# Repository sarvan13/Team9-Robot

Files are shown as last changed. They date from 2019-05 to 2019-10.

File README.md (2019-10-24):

# Team9 - Hedwig

## Hedwig went undefeated in competition!

This repository is contains all of the work that Team 9 (Alex Carbo, Maxwell Yang, Kausik Krishnakumar, Sarvan Gill) produced throughout their summer, with the main focus being on building a fully autonomous robot for a robot competition in August 2019. 

The **ENPH257/** folder contains MATLAB scripts (including data), to investigate thermal waves through the heating of an alumninium rod.

All other folders are pertaining to the robot.

## Robot
Link to the rules and structure of the competition: https://docs.google.com/document/d/1WXgxAmkSgfv2YprMDtSkUyIwbtqzgsT3AemDqi9obIw/edit

Link to news clip on the competition:
https://www.facebook.com/BTCityNewsVAN/videos/583404632190468/

### Microcontrollers
We used 2 STM-32 microcontrollers, giving us a single master controller and a single slave controller. The master handled the navigation aspect of the competition, while the slave controlled the arm movements. The master ran the **robot_test_code/** folder and the slave ran the **slave_code/** folder. 

### CAD
All CAD is in the **Solidworks/** folder. The main assembly is **Robot_V1.SLDASM**. When opening this file it may ask for the loaction of the other files, in which case just point to the correct files. Do not move the files after it has opened. 

The .dxf are the files used to cut the parts using either a laser jet cutter or a water jet cutter. The main purpose of the CAD, was to produce these files for cutting and measurment purposes, so in almost all cases these files were just exported from their respective Solidworks part.

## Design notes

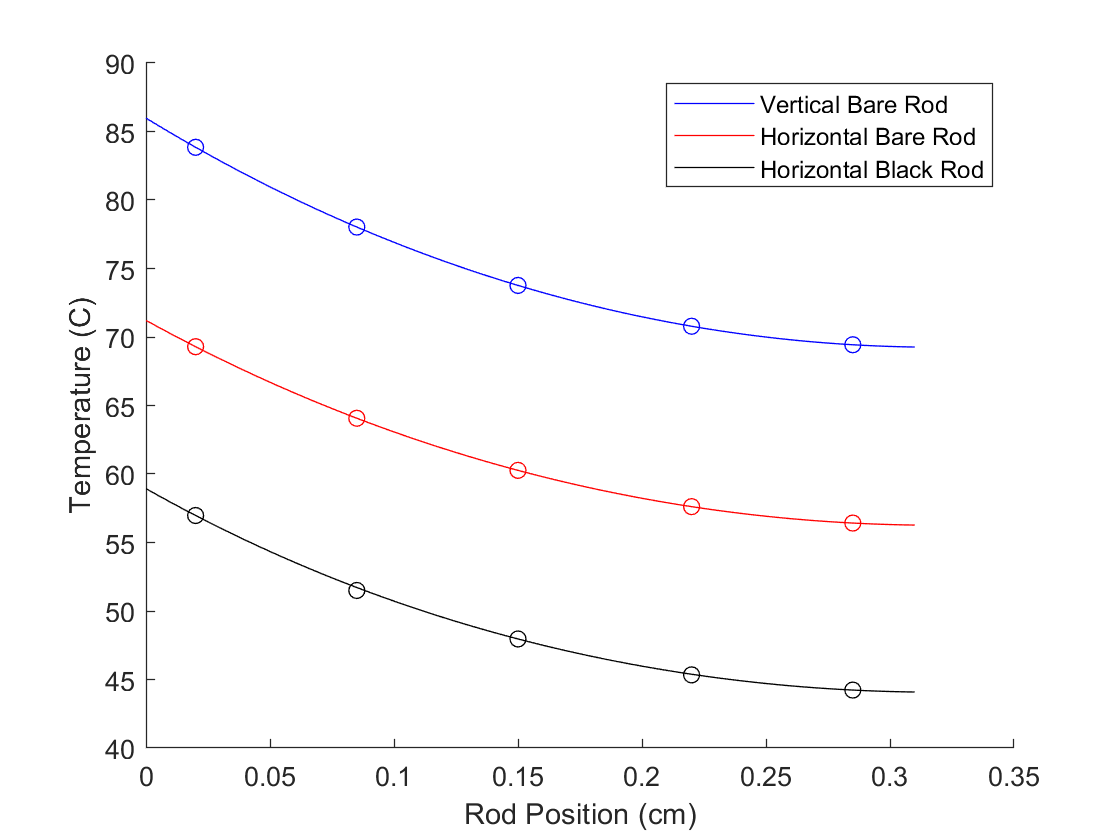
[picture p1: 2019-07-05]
ENPH257/maxwells_sextape_highlights.png

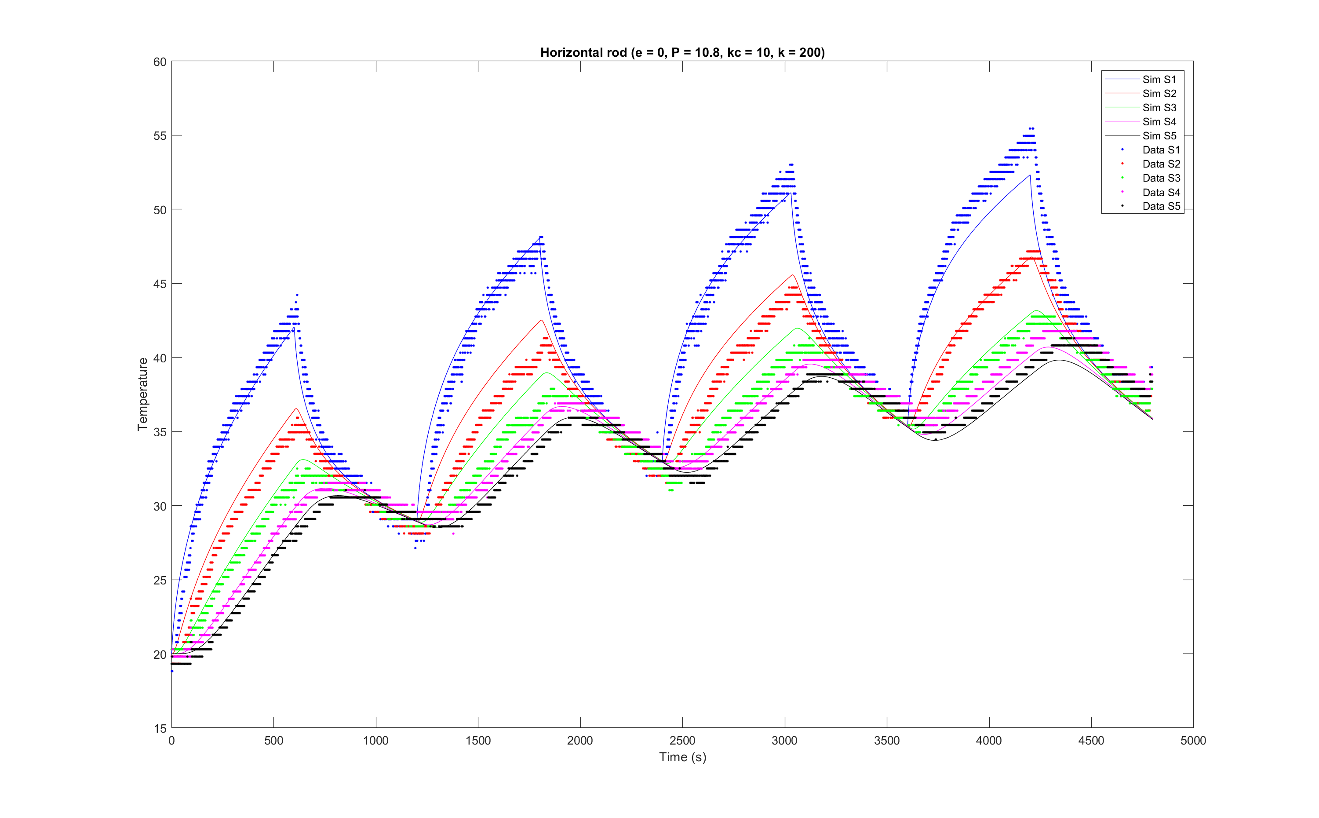
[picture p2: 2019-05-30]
ENPH257/Horizontal(P=10.8,kc=10,k=200).png

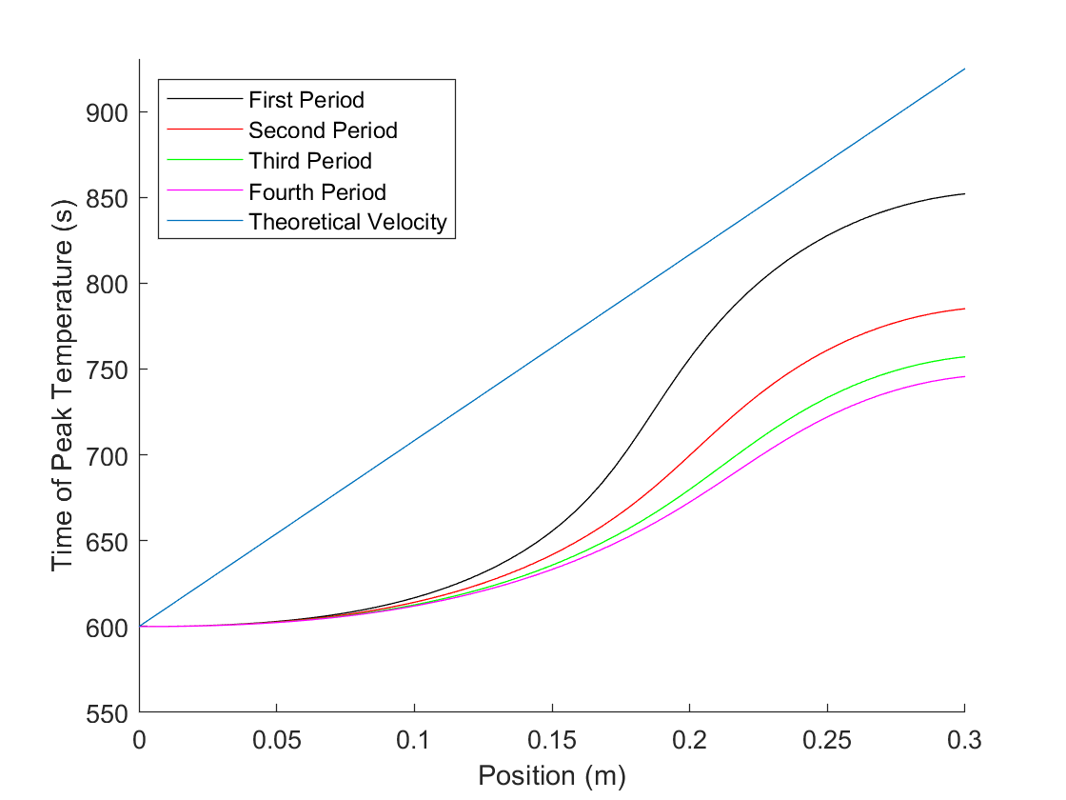
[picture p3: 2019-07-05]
ENPH257/Vala.png

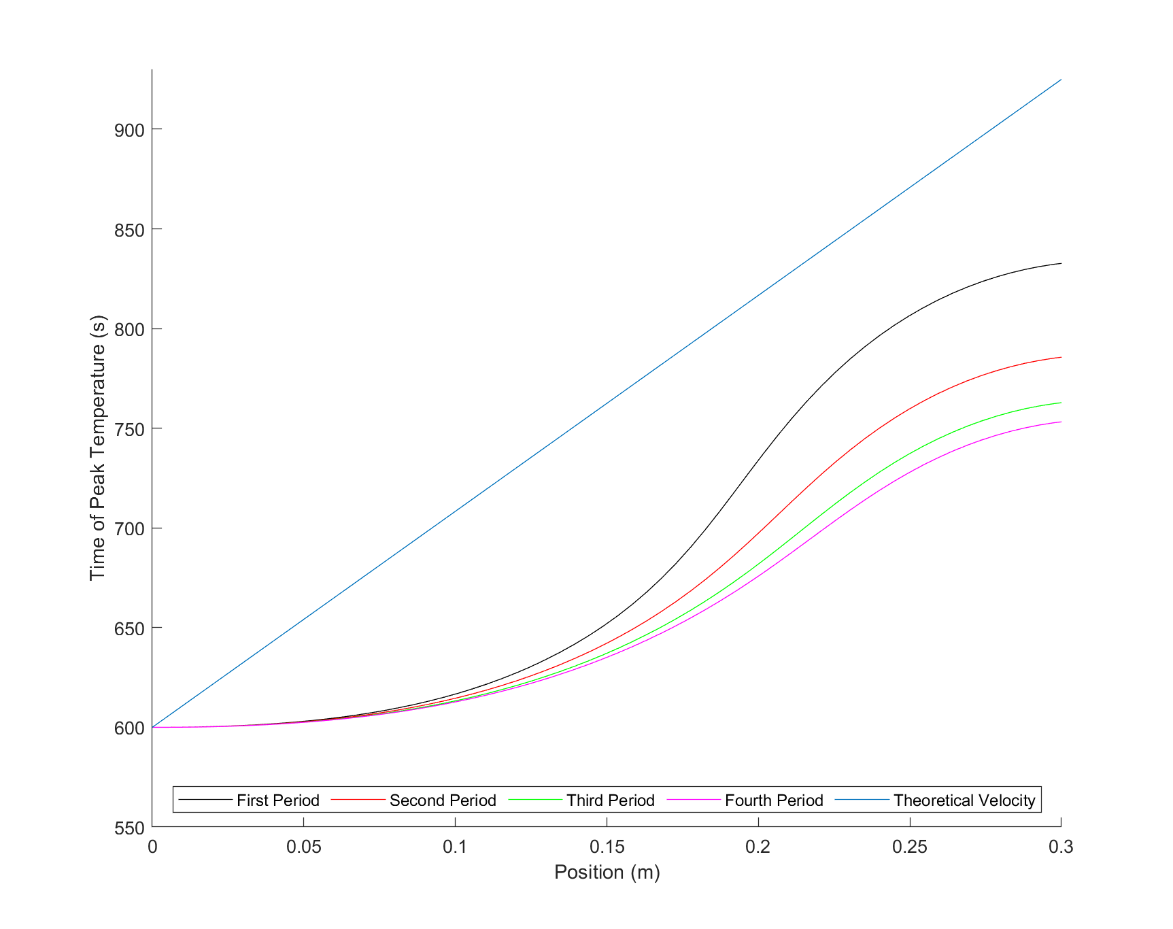
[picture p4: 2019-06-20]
ENPH257/ThermoWaveVelocity.png

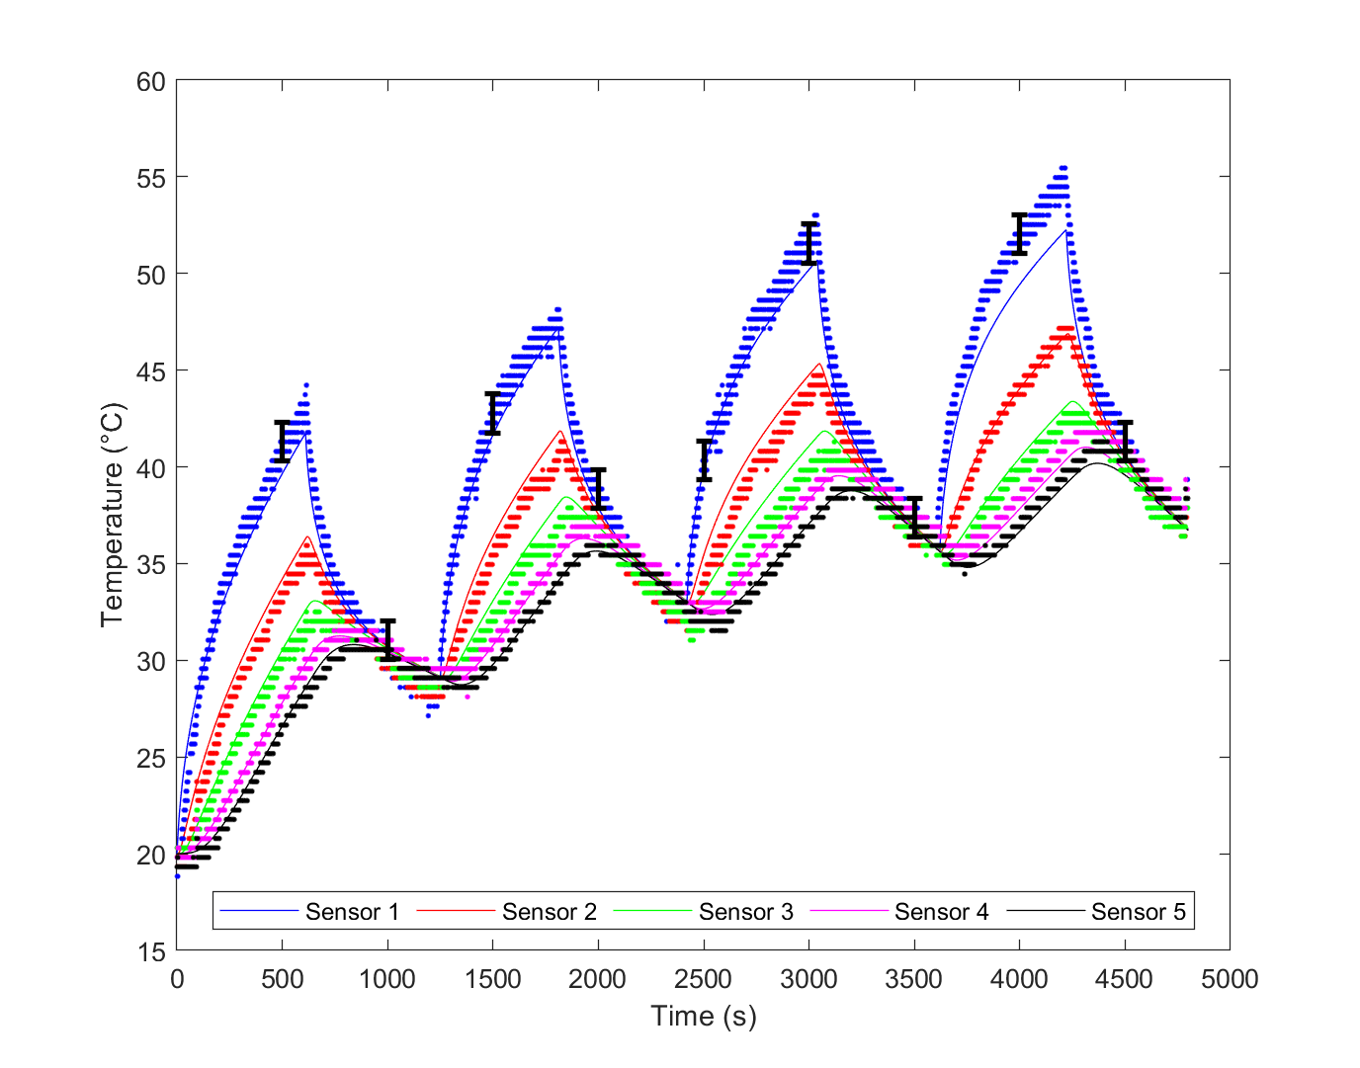
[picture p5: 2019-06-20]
ENPH257/HorizontalFinalBig.png

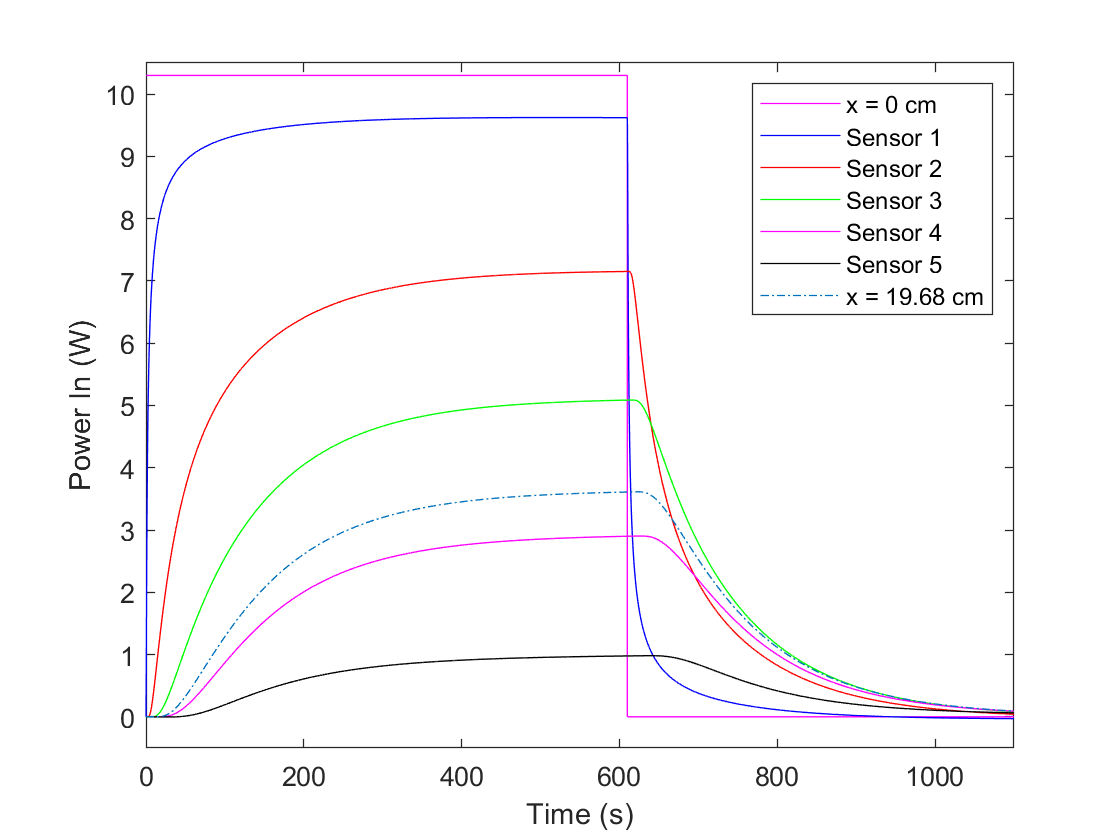
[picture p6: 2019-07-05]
ENPH257/DampedSquareV2.png

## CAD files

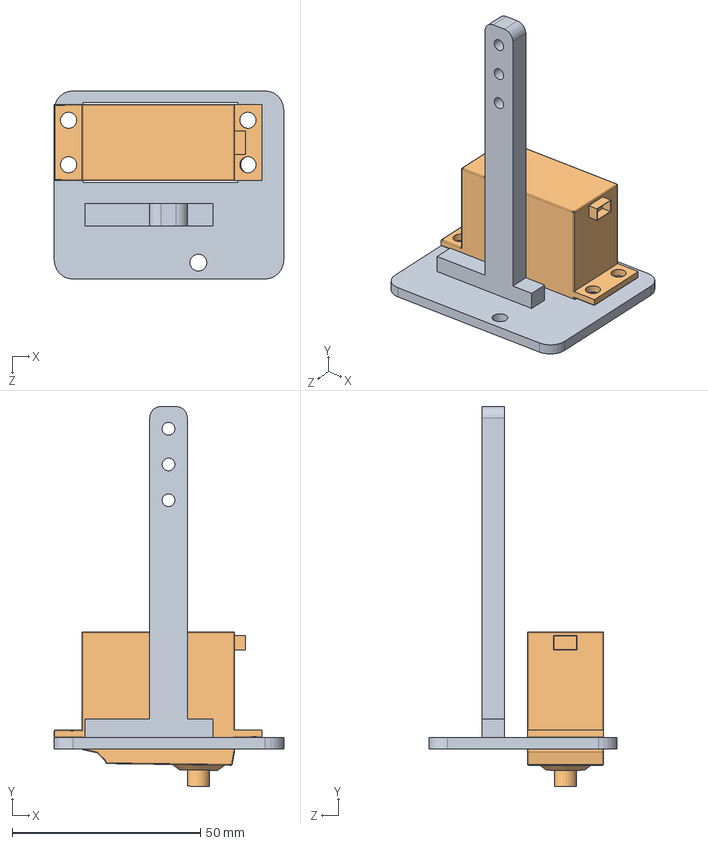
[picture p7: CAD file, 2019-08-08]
Solidworks/CLAWVersion2.SLDASM
61.0 x 100.9 x 50.0 mm
claw
servo motor

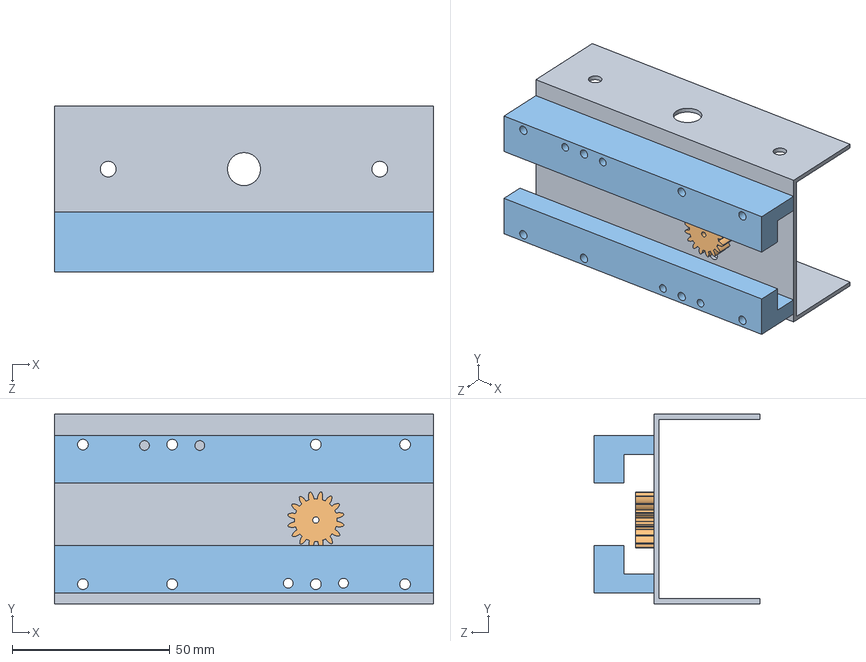
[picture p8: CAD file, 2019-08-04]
Solidworks/InNOut.SLDASM
120.0 x 60.0 x 52.6 mm
NutPlate
spur gear_iso
RackChanel x 2

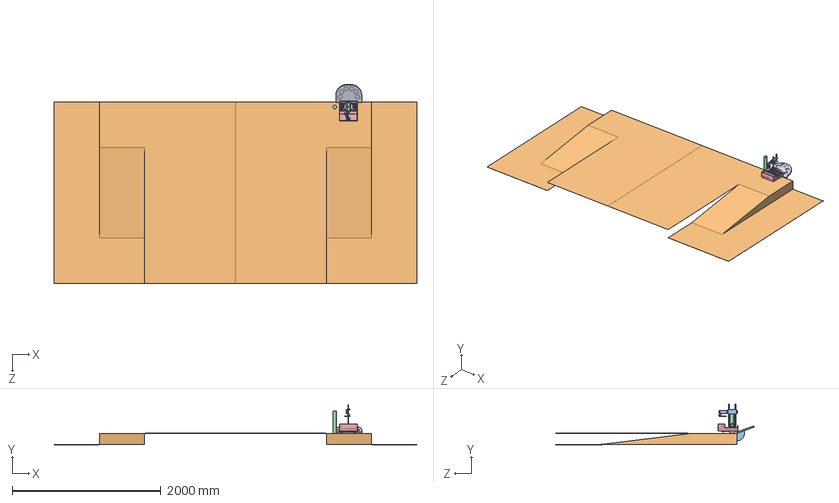
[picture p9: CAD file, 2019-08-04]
Solidworks/Robot_V1.SLDASM
4880.2 x 540.3 x 2674.9 mm
chassis
Motor BarbCole Geared x 2
stepper_motor
lazy susan bearing
caster
wheel x 2
iso_spur_drivetrain_big x 2
iso_spur_drivetrain_small x 2
platter
Motor-BarbCole-Ungeared
spacer_drivetrain_big x 2
spacer_drivetrain_small x 2
spacer_platter_small
LeadScrewMotorBracket
NutPlate
spur gear_iso
RackChanel x 2
Rack
claw
18 teeth claw gear x 2
36 teeth gear

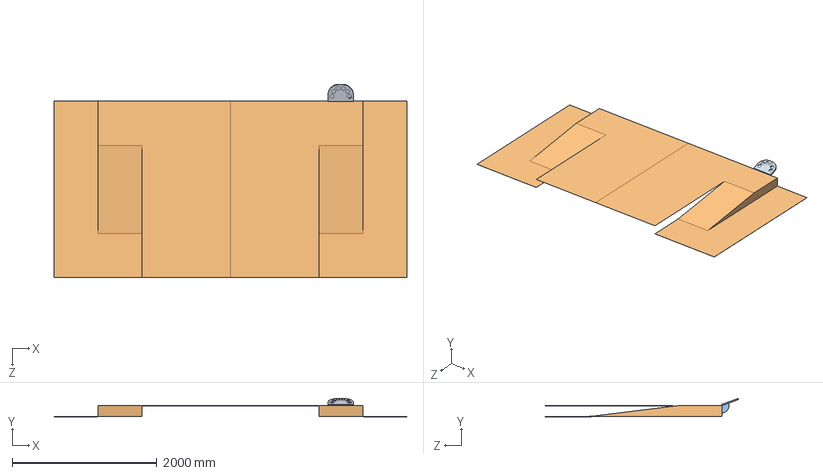
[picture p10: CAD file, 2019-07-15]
Solidworks/Board.SLDASM
4880.2 x 252.5 x 2674.9 mm
gauntlet
ramp & surface skin
bracket for gauntlet

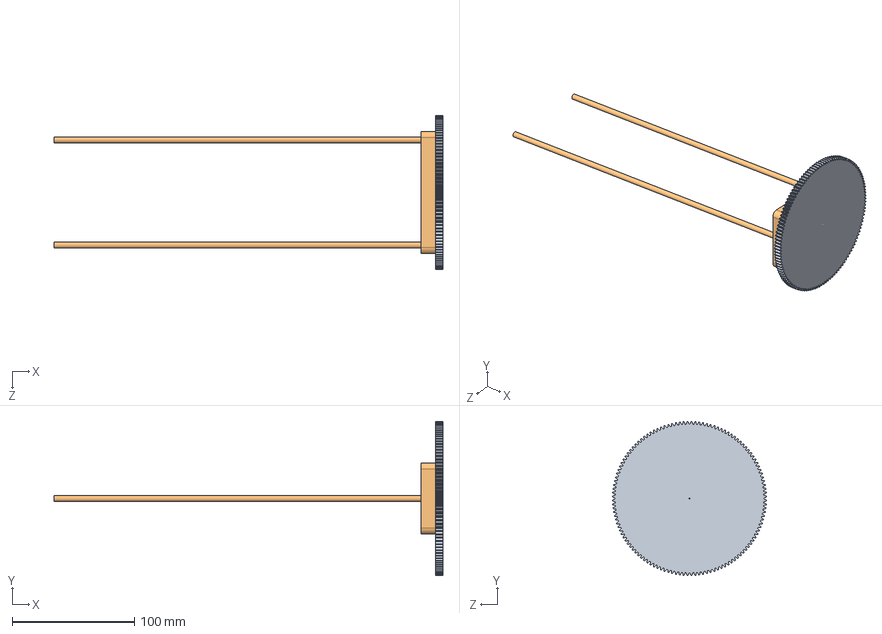
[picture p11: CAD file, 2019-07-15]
Solidworks/NEWPlatter.SLDASM
318.0 x 126.0 x 126.0 mm
spur gear_iso
platter

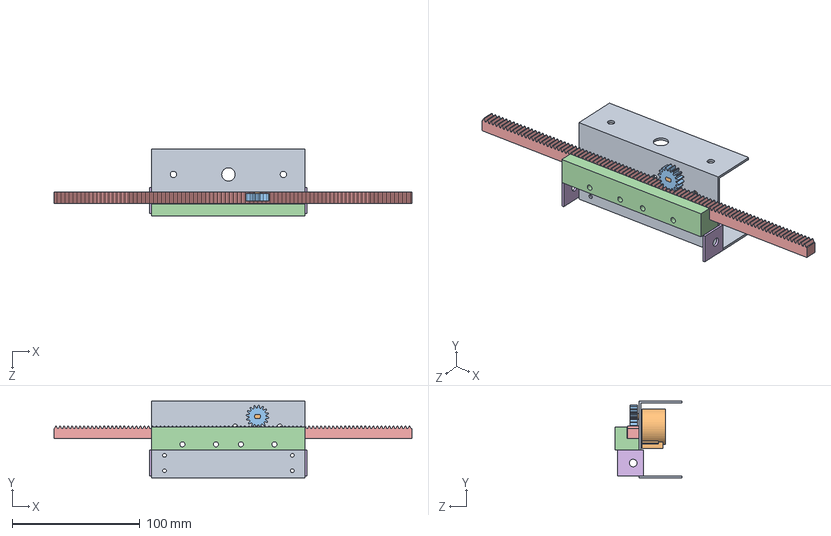
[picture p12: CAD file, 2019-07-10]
Solidworks/CBracketwMotor.SLDASM
280.0 x 60.0 x 52.6 mm
NutPlate
Step Motor 28BYJ-48
spur gear_iso
RackChanel
Rack
Rod2CBraketBraket x 2

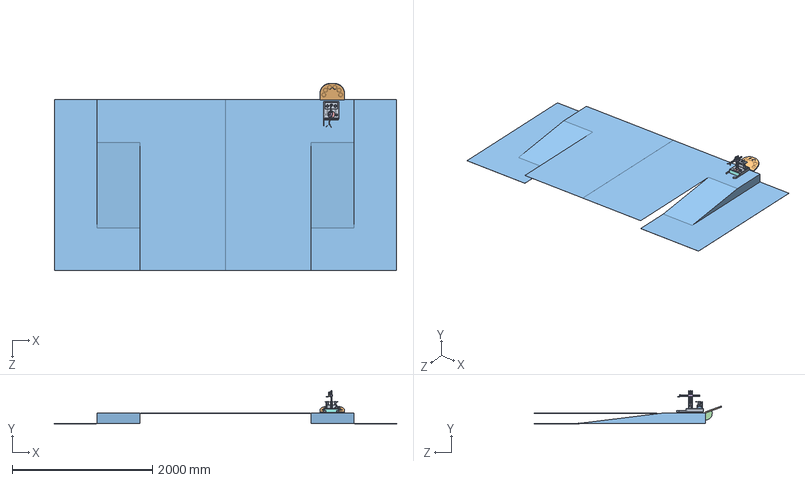
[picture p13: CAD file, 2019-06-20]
Solidworks/grabthembytheplushie.sldasm
4880.2 x 476.8 x 2674.9 mm
chassis
Motor BarbCole Geared x 2
wheel x 2
caster x 2
arm_base
arm_block
arm_extension
FrontBumper
Stepper Motor
gauntlet
ramp & surface skin
bracket for gauntlet

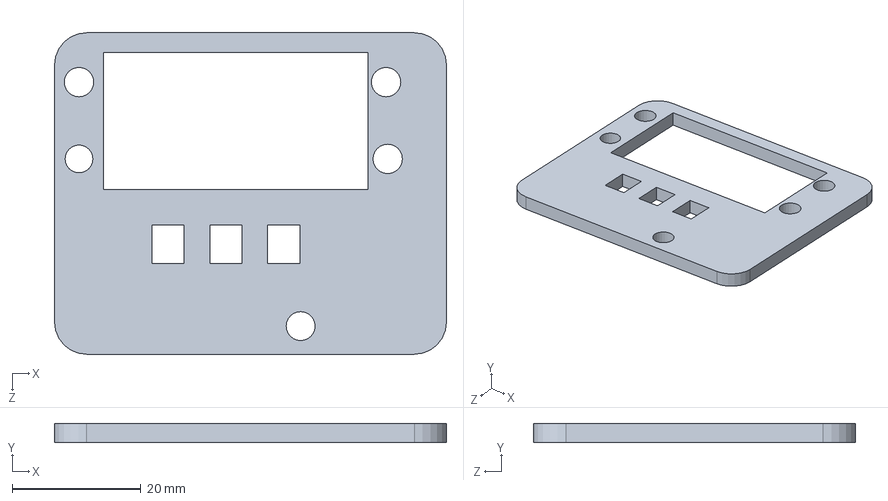
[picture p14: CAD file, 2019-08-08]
Solidworks/claw.SLDPRT
61.0 x 3.00 x 50.0 mm

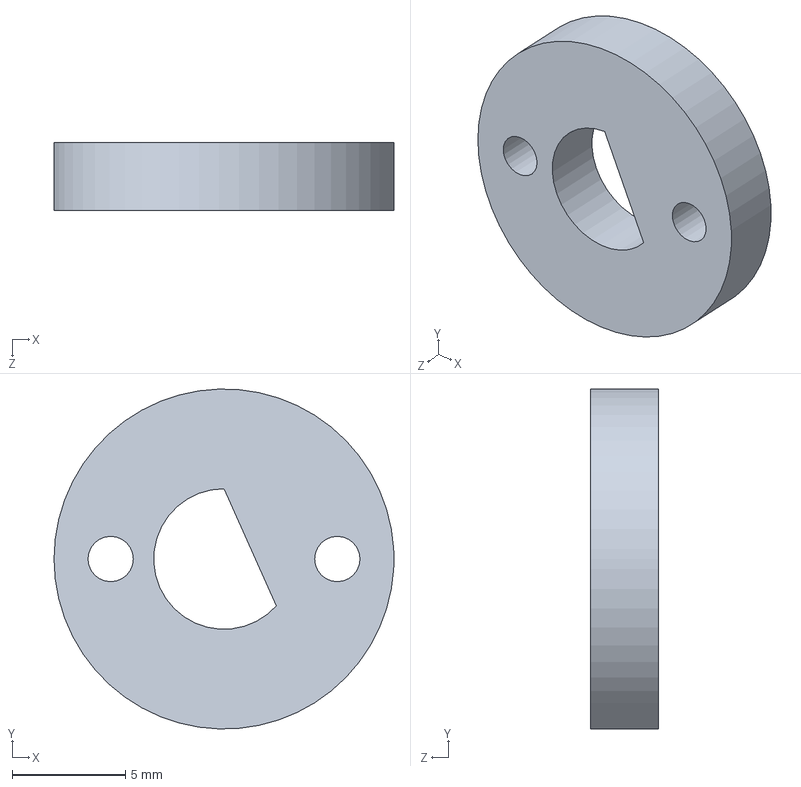
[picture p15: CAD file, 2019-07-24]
Solidworks/cutouts/rotaryEncoderSideFit.SLDPRT
15.0 x 15.0 x 3.00 mm

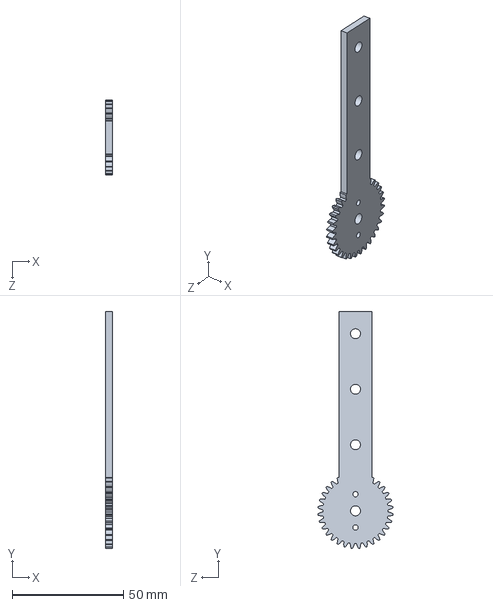
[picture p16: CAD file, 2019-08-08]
Solidworks/gears/FlatBiggerClaw.SLDPRT
3.00 x 106.7 x 33.9 mm

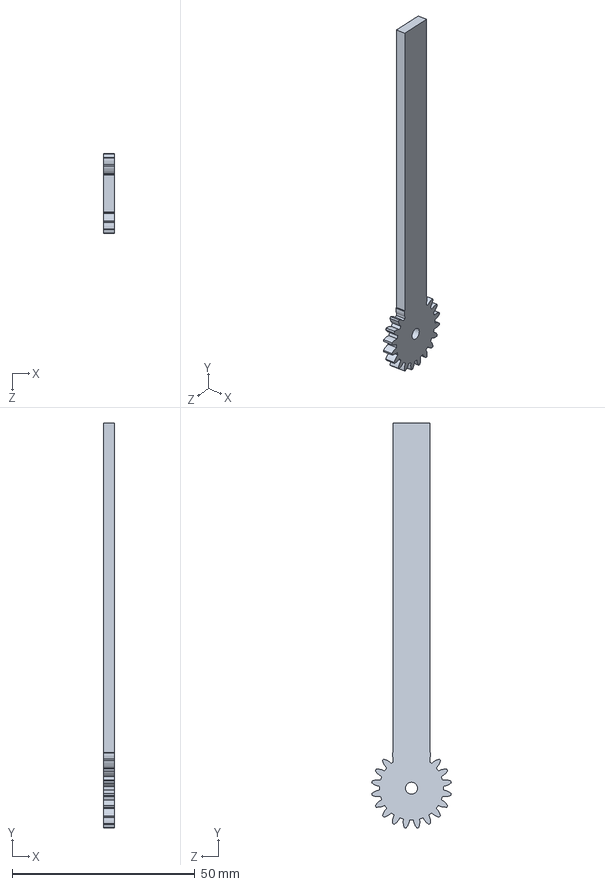
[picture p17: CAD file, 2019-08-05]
Solidworks/gears/20 Tooth Gear Motor.sldprt
3.00 x 110.9 x 21.8 mm

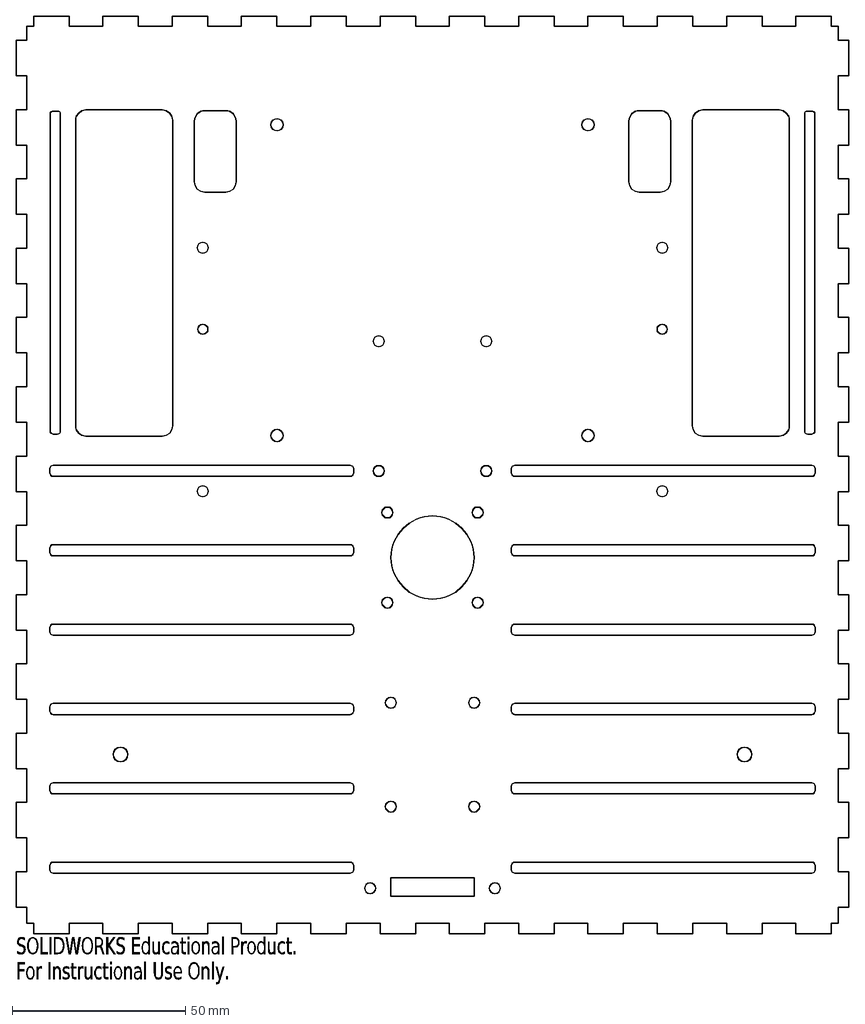
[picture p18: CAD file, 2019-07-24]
Solidworks/cutouts/chassis_cutout_laser.DXF
SOLIDWORKS Educational Product.
For Instructional Use Only.

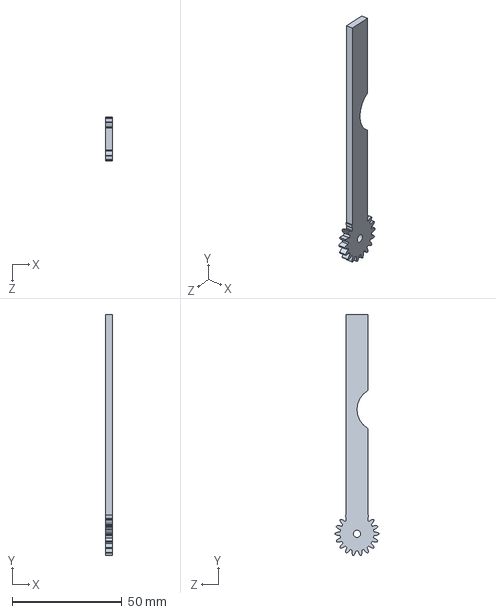
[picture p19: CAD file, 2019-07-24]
Solidworks/gears/18 teeth claw gear.SLDPRT
3.00 x 109.9 x 20.0 mm

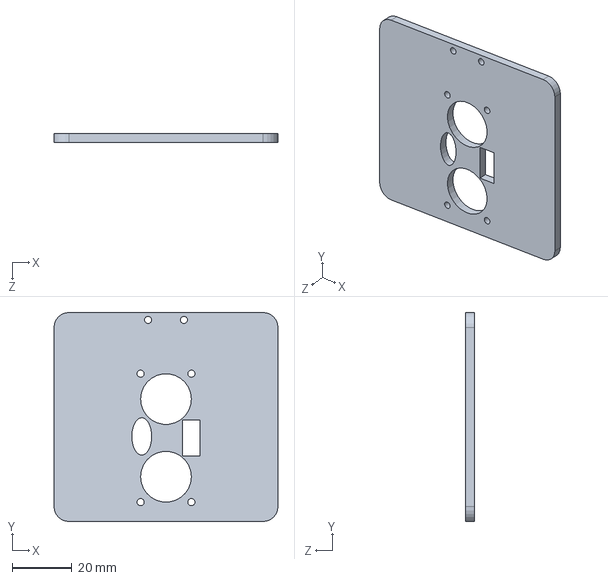
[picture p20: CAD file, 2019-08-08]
Solidworks/SonarHolderPiece.SLDPRT
75.0 x 70.0 x 3.00 mm

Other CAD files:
Solidworks/cutouts/MotorSideFit.SLDPRT
Solidworks/cutouts/chassis_cutout.SLDPRT
Solidworks/gears/36 teeth gear.SLDPRT
Solidworks/rightborder2.DXF
Solidworks/EncoderWasher.DXF
Solidworks/EncoderWasherFat.DXF
Solidworks/EncoderWasherPhat.DXF
Solidworks/FrontBumper.SLDPRT
Solidworks/LeadScrewMotorBracket.SLDPRT
Solidworks/LeadScrewRod.SLDPRT
Solidworks/Motor BarbCole Geared.SLDPRT
Solidworks/Motor-BarbCole-Ungeared.sldprt
Solidworks/NutPlate.DXF
Solidworks/NutPlate.SLDPRT
Solidworks/NutPlateFlat.SLDPRT
Solidworks/Parts - bracket for gauntlet.sldprt
Solidworks/Parts - gauntlet [prelim].sldprt
Solidworks/Parts - ramp.sldprt
Solidworks/Rack.DXF
Solidworks/Rack.sldprt
Solidworks/RackChanel.SLDPRT
Solidworks/RackChanel.STL
Solidworks/RackCircuitMountBottom.DXF
Solidworks/RackCircuitMountBottom.SLDPRT
Solidworks/RackCircuitMountSide.DXF
Solidworks/RackCircuitMountSide.SLDPRT
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

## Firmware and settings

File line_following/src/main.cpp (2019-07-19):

#include <Arduino.h>
#include <Wire.h>
#include <time.h>
#include <math.h>
#include <Adafruit_SSD1306.h>
#include <FreeMono12pt7b.h>
#include <FreeMono9pt7b.h>

// #define MULTIPLEX_OUT PA_0
// #define A PB_3
// #define B PB_13
// #define C PB_4
#define LEFT_REVERSE_PIN PB_1 //ORANGE WIRE
#define LEFT_FORWARD_PIN PB_0 //YELLOW WIRE
#define RIGHT_FORWARD_PIN PA_6 // red, 
#define RIGHT_REVERSE_PIN PA_7 //brown
#define GROUND PB10
#define KP_PIN PA1 //yellow
#define KD_PIN PA2 //orange
#define MULTIPLEX_OUT PA5
#define A PB12  // Left = 000 - Right = 
#define B PB13
#define C PB14

#define TPWM 500
#define CLOCKF 100000


#define DIFTHRESH 300
#define REG_SPEED 300

#define POT_THRESH 10
#define HARDCODE_KP 120 //120
#define HARDCODE_KD 25 //25

float previousError = 0;
float error = 0.0;

int count = 0;

double Kp;
double Kd;
double previous_Kp= 0;
double previous_Kd = 0;

#define OLED_RESET -1
Adafruit_SSD1306 display(OLED_RESET);


void setup()
{
  Serial.begin(115200);
  

  // initialize LED digital pin as an output.
  pinMode(LEFT_FORWARD_PIN, OUTPUT);
  pinMode(LEFT_REVERSE_PIN, OUTPUT);
  pinMode(RIGHT_FORWARD_PIN, OUTPUT);
  pinMode(RIGHT_REVERSE_PIN, OUTPUT); 
  pinMode(GROUND, OUTPUT);
  pinMode(MULTIPLEX_OUT, INPUT_ANALOG);
  pinMode(A,OUTPUT);
  pinMode(B,OUTPUT);
  pinMode(C,OUTPUT);
  pinMode(KP_PIN, INPUT);
  pinMode(KD_PIN, INPUT);



  

  // display.begin(SSD1306_SWITCHCAPVCC, 0x3C);
  // display.clearDisplay();
  // display.setTextSize(1);
  // display.setTextColor(WHITE);
  // display.setCursor(0,0);
  // display.println("OLED Display 128x64");
  // display.setFont(&FreeMono12pt7b);
  // display.drawPixel(0,45,WHITE);
  // display.setCursor(4,45);
  // display.println("Welcome!");
  // display.display();

  //start going forwards
  // digitalWrite(LEFT_FORWARD_PIN, HIGH);
 
  // pwm_start(PB_10, CLOCKF, TPWM, TPWM, 1);

  digitalWrite(A, LOW);
  digitalWrite(B, LOW);
  digitalWrite(C, LOW);

  digitalWrite(GROUND, LOW);

  pwm_start(LEFT_FORWARD_PIN, CLOCKF, TPWM, REG_SPEED, 1);
  pwm_start(RIGHT_FORWARD_PIN, CLOCKF, TPWM, REG_SPEED, 1);

  Kp = analogRead(KP_PIN);
  Kd = analogRead(KD_PIN);
  
  }

void loop()
{

  
  // pwm_start(A, CLOCKF, TPWM, 0, 1);
  // pwm_start(B, CLOCKF, TPWM, 0, 1);
  // pwm_start(C, CLOCKF, TPWM, 0, 1);

  //   float leftSensor = analogRead(MULTIPLEX_OUT);
    
  // pwm_start(B, CLOCKF, TPWM, TPWM, 1);
  // pwm_start(C, CLOCKF, TPWM, TPWM, 1);
  //   float rightSensor = analogRead(MULTIPLEX_OUT);
  
  //0 0 0
  digitalWrite(A, LOW);
  digitalWrite(B, LOW);
  digitalWrite(C, LOW);
  float leftSensor = analogRead(MULTIPLEX_OUT);
  Serial.print(leftSensor); Serial.print(" ");


  //0 1 0
  digitalWrite(A, LOW);
  digitalWrite(B, HIGH);
  digitalWrite(C, LOW);
  float middleSensor = analogRead(MULTIPLEX_OUT);
  Serial.print(middleSensor); Serial.print(" ");


  //1 0 0
  digitalWrite(A, HIGH);
  digitalWrite(B, LOW);
  digitalWrite(C, LOW);
  float rightSensor = analogRead(MULTIPLEX_OUT);
  Serial.print(rightSensor); Serial.print(" ");
  
  
  
  // // 0 1 1  //threshold 300
  // digitalWrite(A, LOW);
  // digitalWrite(B, HIGH);
  // digitalWrite(C, HIGH);
  // float cornerRightSensor = analogRead(MULTIPLEX_OUT);
  // Serial.print(cornerRightSensor); Serial.print(" ");

  // //0 0 1 //threshold 500
  // digitalWrite(A, LOW);
  // digitalWrite(B, LOW);
  // digitalWrite(C, HIGH);
  // float cornerLeftSensor = analogRead(MULTIPLEX_OUT);
  // Serial.print(cornerLeftSensor); Serial.print(" ");


  

  

  

  float previousError = error;



    // display.clearDisplay();
    // display.setFont(&FreeMono9pt7b);
    // display.setCursor(4,20);
    // display.print("L: "); display.println(leftSensor);
    // display.setCursor(4,50);
    // display.print("R: "); display.println(rightSensor);
    // display.display();


    if (rightSensor < DIFTHRESH && leftSensor < DIFTHRESH && middleSensor < DIFTHRESH) {
        if (previousError < 0){
            error = -4;
        } else {
            error = 4;
        }
    } else if (leftSensor < DIFTHRESH && middleSensor < DIFTHRESH){
      error = -2;
    } else if (leftSensor < DIFTHRESH) {
      error = -1;
    } else if (rightSensor < DIFTHRESH && middleSensor < DIFTHRESH) {
      error = 2;
    } else if (rightSensor < DIFTHRESH) {
      error = 1;
    } else {
      error = 0;
    }
    Serial.print(error);

    // Kp = (float) analogRead(KP_PIN);
    // Kd = (float) analogRead(KD_PIN);
    // if(abs(Kp-previous_Kp) > POT_THRESH || abs(Kd - previous_Kd) > POT_THRESH){
    //   display.clearDisplay();
    //   display.setFont(&FreeMono9pt7b);
    //   display.setCursor(4,20);
    //   display.print("KP: "); display.println(Kp);
    //   display.setCursor(4,50);
    //   display.print("KD: "); display.println(Kd);
    //   display.display();
    //   previous_Kp = Kp;
    //   previous_Kd = Kd;
    // }

    float p = HARDCODE_KP * error;
    float d = HARDCODE_KD * (error - previousError);
    // float d = 0;
    float g = (p + d);
    int left_motor_speed = REG_SPEED - g;
    left_motor_speed = constrain(left_motor_speed, 0, TPWM);
    int right_motor_speed = REG_SPEED + g;
    right_motor_speed = constrain(right_motor_speed, 0, TPWM);

    Serial.print(" ");
    Serial.print(left_motor_speed);
    Serial.print(" ");
    Serial.print(right_motor_speed);

    pwm_start(LEFT_FORWARD_PIN, CLOCKF, TPWM, left_motor_speed, 0);
    pwm_start(RIGHT_FORWARD_PIN, CLOCKF, TPWM, right_motor_speed, 0);

    Serial.println();
 }

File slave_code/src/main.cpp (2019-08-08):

#include <Larry.h>
#include <Leviosa.h>
#include <Susan.h>
#include <Talons.h>
#include <Arduino.h>
#include <Wire.h>
#include <time.h>
#include <math.h>
#include <Adafruit_SSD1306.h>
#include <FreeMono12pt7b.h>
#include <FreeMono9pt7b.h>
#include <stdint.h>
#include "PinNames.h"

#define ENCODER_PIN PB12
#define TICKS_PER_REV 24.0 
#define DISTANCE_PER_REV 50.75 //mm (perhaps)

#define FORWARD 1
#define REVERSE -1

#define IN_1 PB5
#define IN_2 PB6
#define OUT PB7

#define STATE_DEBOUNCE 5
// #define GAUNTLET 'G'
// #define LEFT_POST 'L'
// #define RIGHT_POST 'R'

// char wait_for_master();
void pick_up_stone_left();
void pick_up_stone_right();
void gauntlet_disposal();

int current_position;

int arm_counter = 0;

// put your setup code here, to run once:
Larry larry;
Talons talons;
Leviosa leviosa;
Susan susan;

enum arm_state {
  LEFT_POLE,
  RIGHT_POLE
};

void handle_encoder_interrupt();

arm_state arm_side;

void setup() {

  Serial.begin(115200);

  pinMode(ENCODER_PIN, INPUT);
  attachInterrupt(ENCODER_PIN, handle_encoder_interrupt, RISING);
  pinMode(IN_1, INPUT);
  pinMode(IN_2, INPUT);
  pinMode(OUT, OUTPUT);
  digitalWrite(OUT, LOW);



  //SETUP
  leviosa.go_home_hermione();
  leviosa.wingardium_leviosa(85);
  delay(200);
  larry.go_home_larry();
  larry.move_larry(80);
  delay(200);
  susan.go_home_susan();
  talons.open_claw();
 

  }


void loop() {

  int pin_1 = HIGH;
  int pin_2 = HIGH;
  for (int i = 0; i < STATE_DEBOUNCE; i++) {
    pin_1 = pin_1 && digitalRead(IN_1);
    pin_2 = pin_2 && digitalRead(IN_2);
  }

  if(pin_1 == HIGH && pin_2 == HIGH){
          digitalWrite(OUT, HIGH);
          Serial.println("GAUNTLET");
          gauntlet_disposal();
          digitalWrite(OUT, LOW);
          delay(500);
          larry.move_larry(80);
          delay(200);
          susan.turn_susan(100);
          delay(200);
  }else if(pin_1 == HIGH && pin_2 == LOW){
           digitalWrite(OUT, HIGH);
          Serial.println("LEFT_POST");
          pick_up_stone_left();
          digitalWrite(OUT, LOW);
          delay(500);
          susan.turn_susan(100);
          delay(200);
          arm_counter++;
          arm_side = LEFT_POLE;
  }else if(pin_1 == LOW && pin_2 == HIGH){
          digitalWrite(OUT, HIGH);
          Serial.println("RIGHT_POST");
          pick_up_stone_right();
          digitalWrite(OUT, LOW);
          delay(500);
          susan.turn_susan(100);
          delay(200);
          arm_counter++;
          arm_side = RIGHT_POLE;
          
  }else{
    digitalWrite(OUT, LOW);
    Serial.println("NOTHING"); 
  }

  
}


void pick_up_stone_left(){
  digitalWrite(OUT, HIGH);
  if(arm_counter == 1){
    leviosa.wingardium_leviosa(33);
    delay(200);
    susan.go_home_susan();
    delay(200);
  }
  susan.turn_susan(200);
  delay(200);
  if(arm_counter == 0){
    larry.go_far_larry();
    delay(200);
  }else{
    larry.move_larry(64);
    delay(200);
  }
  larry.move_larry(larry.current_position + 20);
  if(arm_counter == 1){
    susan.set_sweep_angle(30);
  }
  susan.point_to_min_distance();
  delay(400);
  if(arm_counter == 0){
    larry.go_far_larry();
    delay(200);
  }else{
    larry.move_larry(64);
    delay(200);
  }
 
  larry.move_larry(larry.current_position + 8);
  delay(200);
  talons.close_claw();
  delay(1000);
  if(arm_counter == 0){
    leviosa.wingardium_leviosa(92);
    delay(200);
    larry.go_far_larry();
    delay(200);
    leviosa.wingardium_leviosa(100);
    delay(200);
  }else{
    leviosa.wingardium_leviosa(43);
    delay(200);
    larry.move_larry(64);
    delay(200);
    leviosa.wingardium_leviosa(50);
    delay(200);
  }
  susan.go_home_susan();
  delay(200);
  larry.move_larry(90);

  digitalWrite(OUT, LOW);
}

void pick_up_stone_right(){
  digitalWrite(OUT, HIGH);
  if(arm_counter == 1){
    leviosa.wingardium_leviosa(35);
    delay(200);
    susan.go_home_susan();
    delay(200);
  }
  susan.turn_susan(-160);
  delay(200);
  larry.go_far_larry();
  delay(200);
  larry.move_larry(larry.current_position + 20);
  if(arm_counter == 1){
    susan.set_sweep_angle(40);
  }
  susan.point_to_min_distance();
  delay(400);
  larry.go_far_larry();
  delay(200);
  if(arm_counter == 0){
    larry.move_larry(larry.current_position + 8);
  }
  
  delay(200);
  talons.close_claw();
  delay(1000);
  if(arm_counter == 0){
    leviosa.wingardium_leviosa(92);
    delay(200);
    larry.go_far_larry();
    delay(200);
    leviosa.wingardium_leviosa(100);
    delay(200);
  }else{
    leviosa.wingardium_leviosa(43);
    delay(200);
    larry.go_far_larry();
    delay(200);
    leviosa.wingardium_leviosa(50);
    delay(200);
  }
  susan.go_home_susan();
  delay(200);
  larry.move_larry(90);
  digitalWrite(OUT, LOW);
}

void gauntlet_disposal(){
  digitalWrite(OUT, HIGH);
  larry.move_larry(80);
  delay(200);
  leviosa.go_home_hermione();
  delay(200);
  susan.go_home_susan();
  if(arm_side == LEFT_POLE){
    if(arm_counter == 1){
      susan.turn_susan(10);
      delay(200);
      larry.go_home_larry();
      delay(200);
      talons.open_claw();
    }else{
      susan.turn_susan(40);
      delay(200);
      larry.go_home_larry();
      delay(200);
      talons.final_open_claw();
    }
  }else{
    if(arm_counter == 1){
      susan.turn_susan(10);
      delay(200);
      larry.go_home_larry();
      delay(200);
      talons.open_claw();
    }else{
      susan.turn_susan(43);
      delay(200);
      larry.go_home_larry();
      delay(200);
      talons.final_open_claw();
    }
  }
  

  digitalWrite(OUT, LOW);
}

void handle_encoder_interrupt(){
  if (larry.state == FORWARD){
    larry.current_position -= DISTANCE_PER_REV / TICKS_PER_REV;
  }
  else if (larry.state == REVERSE){
    larry.current_position += DISTANCE_PER_REV / TICKS_PER_REV;
  }
  if(larry.current_position < 0){
    larry.current_position = 0;
  } 

}

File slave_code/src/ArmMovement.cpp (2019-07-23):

// #include <ArmMovement.h>
// #include <Arduino.h>
// #include <Wire.h>
// #include <time.h>
// #include <math.h>
// #include <Adafruit_SSD1306.h>
// #include <FreeMono12pt7b.h>
// #include <FreeMono9pt7b.h>
// #include <stdint.h>
// #include "PinNames.h"

// //Home Pins
// #define RACK_LIMIT_PIN PB_5
// #define SUSAN_LIMIT_PIN PB_4
// #define LEAD_SCREW_LIMIT_PIN PB_3
// //Distance Finding Pins
// #define RACK_ENCODER_PIN PB_12
// #define CLAW_LIMIT_PIN PB_13
// #define QRD_ENCODER_PIN PA_5
// //Motor Pins
// #define IN_PIN PA_1 //maybe
// #define OUT_PIN PA_0 //maybe
// #define UP_PIN PA_3 //maybe
// #define DOWN_PIN PA_2 //maybe

// #define REG_SPEED 500
// #define TPWM 500
// #define CLOCKF 100000

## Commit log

2019-05-23 Code used from Lab 2 for the IR detection circuit Detects the difference between a 1kHz signal and 10kHz signal given a certain threshold to distinguish for noise.
    [IR_Detection.cpp]
2019-05-24 Code for generating a PWM motor control pulse. Currently outputs 2 PWM pulses, adjusting the period with a single analog input. Pulses are never on at the same time.
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2019-06-11 Added Solidworks files to repo
    [Motor BarbCole Geared.SLDPRT, Motor BarbCole Ungeared.SLDPRT, Motor-BarbCole-Geared.sldprt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]
2019-06-12 Ready for presentation
    [FrontBumper.SLDPRT, PotentialNewChassis.SLDPRT, arm_block.sldprt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]
2019-06-18 Added stepper motor model
    [Stepper Motor.SLDPRT, Stepper Motor.STEP, chassis.sldprt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]
2019-06-18 Random commit
    [grabthembytheplushie.sldasm]
2019-06-18 Added board to assembly
    [Board.SLDASM, Stepper Motor.STEP, bracket for gauntlet.sldprt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]
2019-06-18 Rearranged board
    [grabthembytheplushie.sldasm]
2019-06-20 Started new assembly, began chassis
    [Motor BarbCole Geared.SLDPRT, Motor BarbCole Ungeared.SLDPRT, Motor-BarbCole-Geared.sldprt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]
2019-06-20 Reoriented assembly
    [Robot_V1.SLDASM]
2019-06-20 PID improved
    [Board.SLDASM, Motor BarbCole Geared.SLDPRT, Motor BarbCole Ungeared.SLDPRT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]
2019-06-21 Updated chassis
    [Robot_V1.SLDASM, chassis.sldprt, motor_mount_left.DXF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]
2019-06-21 Updated motor brackets
    [Robot_V1.SLDASM, chassis.sldprt]
2019-06-21 Added gears for drivetrain
    [Robot_V1.SLDASM, chassis.sldprt, iso_spur_drivetrain_big.SLDPRT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]
2019-06-22 Did stuff
    [Robot_V1.SLDASM, caster.sldprt, iso_spur_drivetrain_big.SLDPRT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]
2019-07-02 idk i updated the wheels or whatever
    [Robot_V1.SLDASM, Stepper Motor.SLDPRT, iso_spur_drivetrain_big_cutout.DXF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]
2019-07-02 Added chassis cutout and working drivetrain gears
    [Robot_V1.SLDASM, chassis_cutout.DXF, chassis_cutout.SLDPRT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]
2019-07-03 commit from lab low battery
    [Robot_V1.SLDASM, chassis.sldprt]
2019-07-04 updated chassis for aluminum, includes sides perforations
    [Robot_V1.SLDASM, caster.sldprt, chassis.sldprt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]
2019-07-04 SolidWorks Pusshhshshshshshj
    [Robot_V1.SLDASM, chassis.sldprt]
2019-07-04 aluminum chassis v1 done
    [Robot_V1.SLDASM, chassis.sldprt]
2019-07-04 created platter gears 5:1
    [PotentialNewChassis.SLDPRT, Robot_V1.SLDASM, chassis.sldprt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]
2019-07-08 Changed drivetrain to 6:1, added spacers, started arm lift
    [Robot_V1.SLDASM, chassis.sldprt, iso_spur_drivetrain_big.SLDPRT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]
2019-07-08 Added cutouts
    [Robot_V1.SLDASM, chassis_cutout.SLDPRT, chassis_cutout_laser.DXF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]
2019-07-08 First iteration of funnel design
    [funnel_insert_v1.SLDPRT]
2019-07-08 Old Chasis Cutout
    [chassis_cutout.DXF]
2019-07-08 small solidworks and code
    [Robot_V1.SLDASM, platter.SLDPRT]
2019-07-09 Funnel Stuff
    [Assem1.SLDASM, Robot_V1.SLDASM, body.SLDPRT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]
2019-07-09 Alex july 8th
    [Robot_V1.SLDASM, platter.SLDPRT]
2019-07-09 Removed the incorrect stepper motor files and added the new correct small stepper motor.
    [Assem1.SLDASM, Step Motor 28BYJ-48.SLDPRT, body.SLDPRT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]
2019-07-09 small change
    [platter.SLDPRT]
2019-07-09 Cbracket with motor attached is now done.
    [CBracketwMotor.SLDASM, NutPlate.SLDPRT, Step Motor 28BYJ-48.SLDPRT]
2019-07-09 solidworks stuff, changed lazy susan gears, mates, sizes, location of holes on lazy susan platter to reflect reality.
    [124 Teeth ISO Gear 6mm.sldprt, 126 teeth gear.SLDPRT, 36 teeth gear.SLDPRT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]
2019-07-10 Wheels on both sides model, more accurate model for wheels and gears - will prob need changing when we change the ratio...
    [36GearThin.sldprt, Robot_V1.SLDASM]
2019-07-10 Rack and Pinion CAD. Need to adjust hole for pinion to fit the stepper.
    [16TeethGearMod1.SLDPRT, CBracketwMotor.SLDASM, NutPlate.SLDPRT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]
2019-07-10 Added battery holders
    [big_battery_holder.SLDPRT, small_battery_holder.SLDPRT]
2019-07-12 Rack and Pinion actually done this time. Minus the gear hole.
    [InNOut.SLDASM, NutPlate.SLDPRT, Rack.sldprt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]
2019-07-12 Motor bracket for lead screw
    [126 teeth gear.SLDPRT, 36GearThin.sldprt, LeadScrewMotorBracket.SLDPRT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]
2019-07-13 < 2 weeks till time trials...
    [LeadScrewMotorBracket.SLDPRT, Robot_V1.SLDASM]
2019-07-14 I think this is just the dxf files and the adjusted gears and stuff for the Rack and Pinion.
    [16TeethGearMod1.SLDPRT, 16TeethGearMod1v1.DXF, 16TeethGearMod1v1Offset.DXF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]
2019-07-15 Updated chassis and platter, added claw
    [124 Teeth ISO Gear 6mm.sldprt, 126 teeth gear.SLDPRT, 16TeethGearMod1.SLDPRT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]
2019-07-15 Updated chassis slits and border
    [36 teeth gear.SLDPRT, Robot_V1.SLDASM, chassis.sldprt]
2019-07-23 Slave Code but not working on sarvans computer.
    [ArmMovement.cpp, Larry.cpp, Leviosa.cpp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]
2019-07-23 Servo test
    [18 teeth claw gear.SLDPRT, 20 Tooth Gear Motor.sldprt, 36 teeth gear.DXF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]
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2019-07-24 Changed MAX_DISTANCE for Larry to 100 to account for error build up
    [Larry.cpp, main.cpp]
2019-07-25 top stablilizer
    [InNOut.SLDASM, NutPlate.SLDPRT, Robot_V1.SLDASM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]
2019-07-25 tested and fixed sonar code
    [Larry.cpp, Susan.cpp, main.cpp]
2019-07-26 Just main boutta mess some stuff up
    [LeadScrewRod.SLDPRT]
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2019-07-30 Maxwell's CAD for the bumpers
    [InNOut.SLDASM, Robot_V1.SLDASM, backborder.DXF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]
2019-07-30 Maxwell's chasis cad again
    [backbordernew.DXF, chassis.sldprt, frontbordernewnew.DXF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]
2019-08-04 test communication btwn pills, some solidworks
    [SonarHolderPiece.SLDPRT, claw.SLDPRT]
2019-08-06 new claw design
    [CLAWVersion2.SLDASM, FlatBiggerClaw.SLDPRT, SonarHolderPiece.SLDPRT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]
